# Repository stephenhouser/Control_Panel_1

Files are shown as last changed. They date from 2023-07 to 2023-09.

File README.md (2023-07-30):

# Control Panel

The old-school hard-switch control panel for Home Automation.

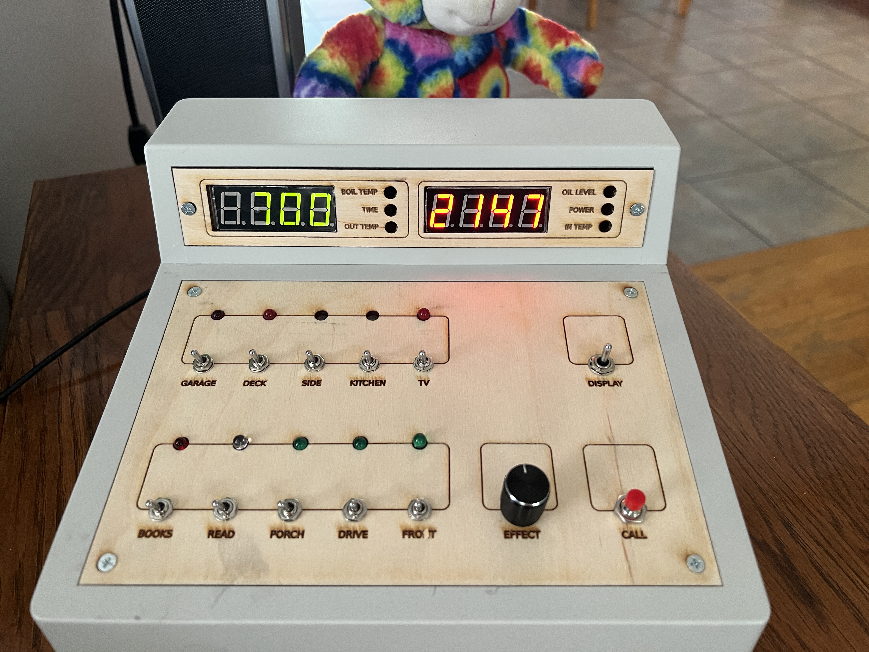
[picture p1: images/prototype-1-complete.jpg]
Breadboard Prototype


This project has a few parts, each documented in their own section below.

- Project Box from Amazon; link and description
- Base and Top panels; SVG files for a laser cutter
- PCBs for Base and Top panels; KiCad PCB designs for manufacture

# Project Box

The project box is a [BUD Industries PC-11495 Plastic Style F Box 9" W x 5" H x 8.5" D, Natural](
https://www.amazon.com/gp/product/B005T98PQS/ref=ppx_yo_dt_b_search_asin_title?ie=UTF8&psc=1) which I found on Amazon for ~$32 USD. The [Dimensions](https://www.budind.com/wp-content/uploads/2019/01/hb11495.pdf) are available from BUD Industries (thank you!)

Another option, without the top display is the [BUD Industries PC-11493 Plastic Style F Box 9" L x 8.5" W x 1.98" H, Natural](https://www.amazon.com/gp/product/B005T592P0/ref=ppx_yo_dt_b_search_asin_title?ie=UTF8&psc=1) for ~$30 USD. The [Dimensions](https://www.budind.com/wp-content/uploads/2019/01/hb11493.pdf) are available from BUD Industries (thank you!)

You can find details on these boxes in general from [BUD Industries](https://www.budind.com/series/general-use-boxes/plasticase-style-f-plastic-cases-2/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)

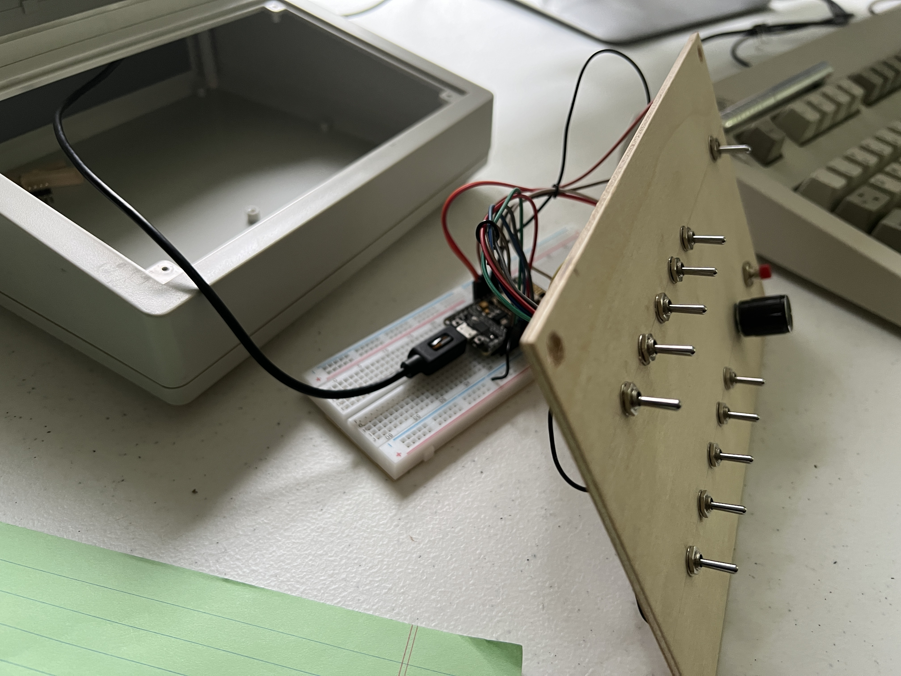
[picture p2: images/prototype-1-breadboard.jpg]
Breadboard Prototype


# Base and Top Panels

Look in the Box_Panels directory. These are SVG files for a laser cutter

# PCBs for Base and Top panels

Uses KiCad v7.x for two PCB's; Control Board and Display Board.

Control Board
---

- Version 1.0 sent to fab on 7/17/2023

Components:

-  1 x ESP32 DevKit C ([Amazon](https://www.amazon.com/AITRIP-ESP32-DevKitC-Development-ESP32-WROOM-32D-Compatible/dp/B08HMJ1X6W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))
- 16 x Addressable RGB LEDs ([sparkfun](https://www.sparkfun.com/products/12986))
- 10 x 2-position SPST Toggle Switches ([Amazon](https://www.amazon.com/MTS-101-Position-Miniature-Toggle-Switch/dp/B0799LBFNY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))
-  1 x 3-position SPST Toggle Switch ([Amazon](https://www.amazon.com/Twidec-Momentary-Miniature-Waterproof-MTS-123-MZ/dp/B07VHCB1Q4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))
- 10 x 1N4148 Diodes
-  1 x Rotary Encoder + Knob ([Amazon](https://www.amazon.com/gp/product/B07DM2YMT4/ref=ppx_yo_dt_b_search_asin_title?ie=UTF8&psc=1))
-  1 x Mini pushbutton switch ([Amazon](https://www.amazon.com/Momentary-Spring-Return-Self-Return-Pushbutton-Switches/dp/B09DJY5Y5L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))

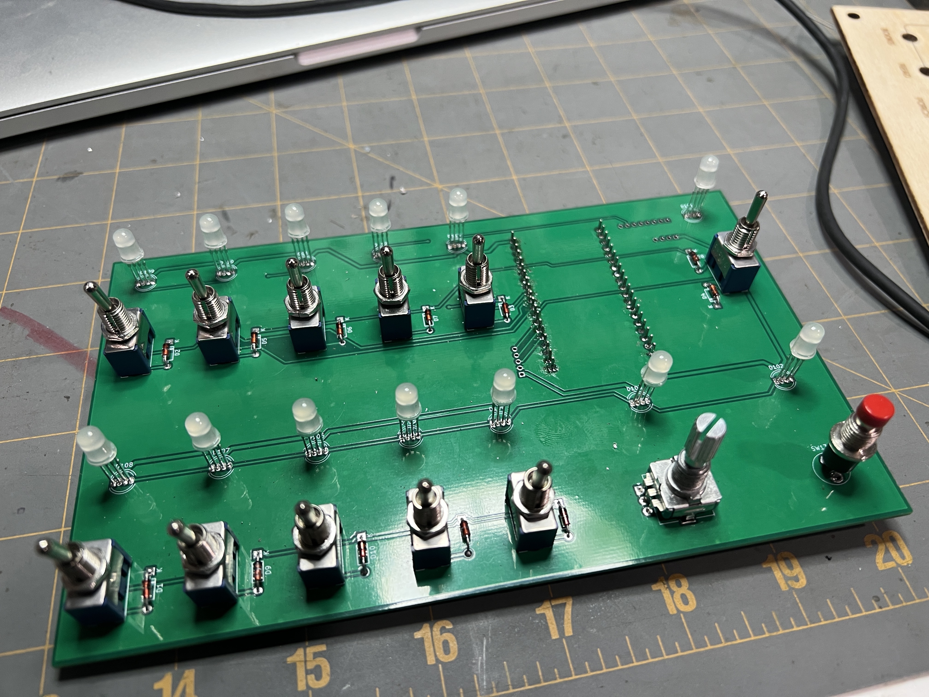
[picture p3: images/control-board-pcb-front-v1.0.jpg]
Control Board PCB Front
)
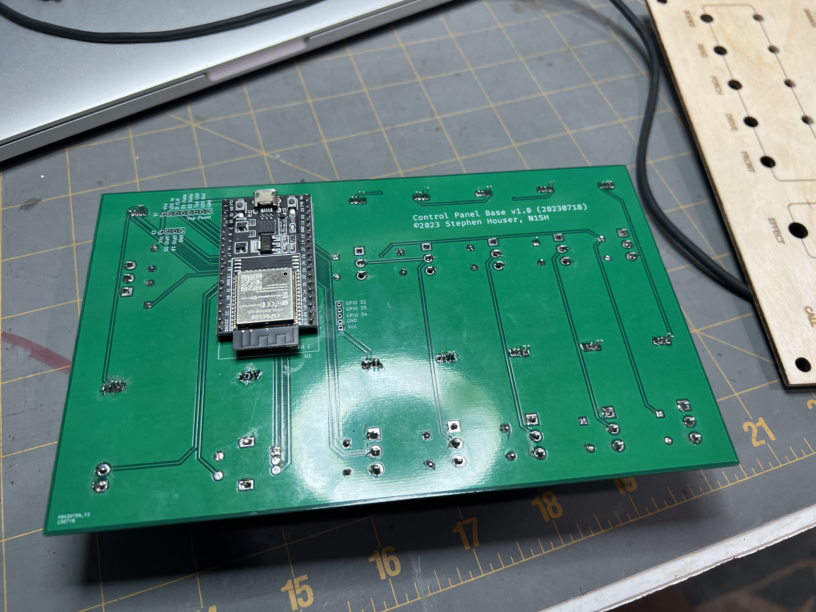
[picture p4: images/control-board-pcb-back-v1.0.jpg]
Control Board PCB Back
)

Display Board
---
Display Board not yet created.

Components:

-  2 x 0.56" LED Display Digital Tube Clock Module 4 Digit ([Amazon](https://www.amazon.com/gp/product/B0BB72R6RW/ref=ppx_yo_dt_b_asin_title_o03_s00?ie=UTF8&psc=1))

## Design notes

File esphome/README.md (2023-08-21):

# ESPHome Control Panel Configuration

This directory holds the configuration for the control panel with [ESPHome](https://esphome.io) and [HomeAssistant](https://www.home-assistant.io).

- **components**: ESPHome custom component for the `matrix_keyboard`. Will need to be copied into the ESPHome directory to be included into the YAML configurations.

- **blueprints**: contains blueprintes for ESPHome to configure each toggle switch to be connected to an LED on the panel and a device within HomeAssistant. Each toggle and it's associated LED should be connected to a `control-panel-switch`

- **common**: contans some common includes to be used in ESPHome. These are optional. If not used, the `include` statements will need to be removed from the YAML files.

- **Example Congifurations**:
  - `living-room-cp.yaml`: Living Room Control Panel (production)
  - `dev-control-panel.yaml`: Development Control Panel (development, Office)
  - `dev-sound.yaml`: Experiment with i2s sound

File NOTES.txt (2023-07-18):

Getting Started in KiCad
https://docs.kicad.org/6.0/en/getting_started_in_kicad/getting_started_in_kicad.html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

in ~/Documents/KiCad
	https://forum.digikey.com/t/importing-the-digi-key-kicad-library-into-kicad-5-0-0/4075
```	
git clone https://github.com/Digi-Key/digikey-kicad-library.git
git clone https://github.com/jdunmire/kicad-ESP8266
```

toggle switch: 
pushbutton: PS1024ALRED, 
https://www.digikey.com/en/products/base-product/e-switch/141/PS1024/476669
https://www.digikey.com/en/products/detail/e-switch/PS1024ALRED/81539
https://media.digikey.com/pdf/Data%20Sheets/E-Switch%20PDFs/PS1024ablk%20Drawing.pdf

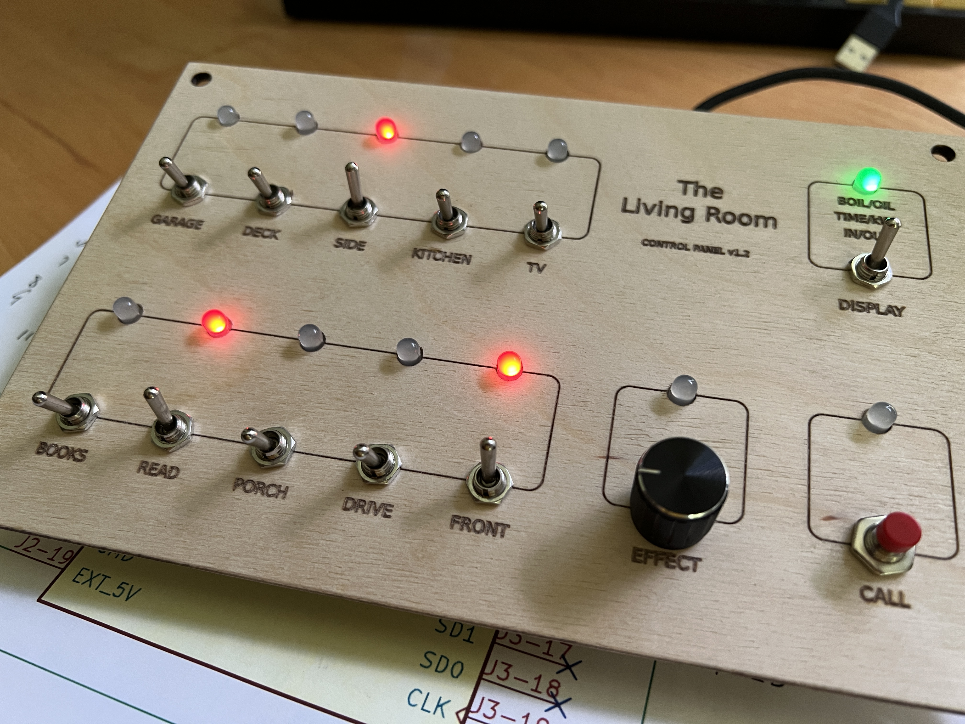
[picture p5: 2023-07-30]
images/control-panel-v1.2.jpg

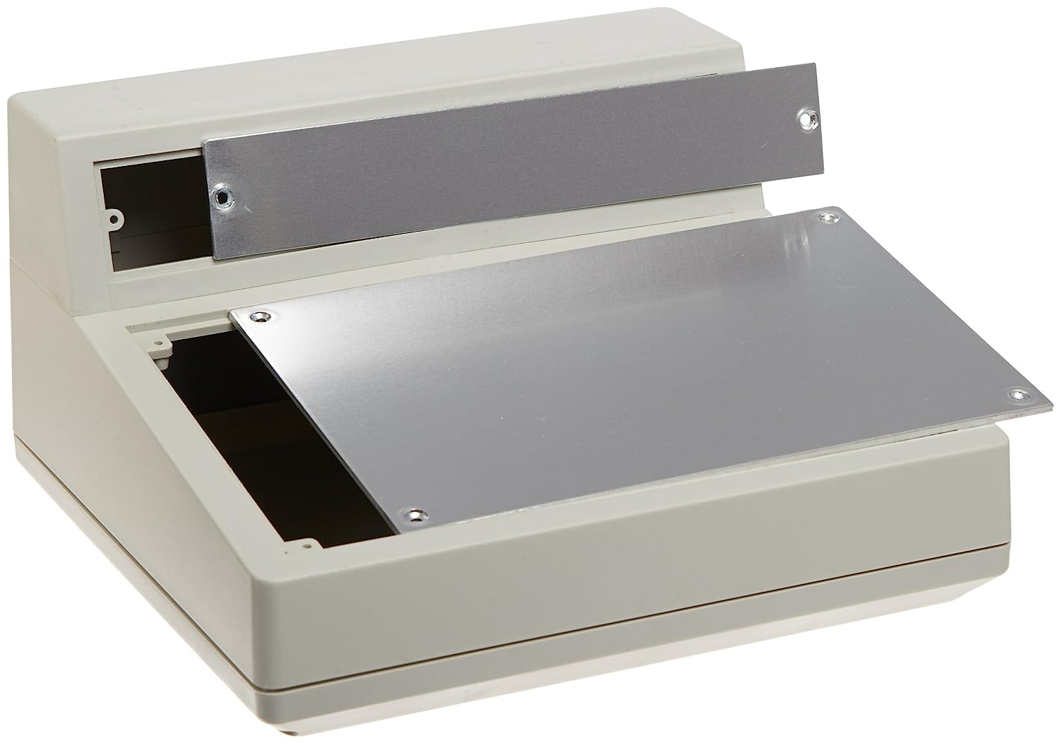
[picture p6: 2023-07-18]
Box_Panels/PC-11495.jpg

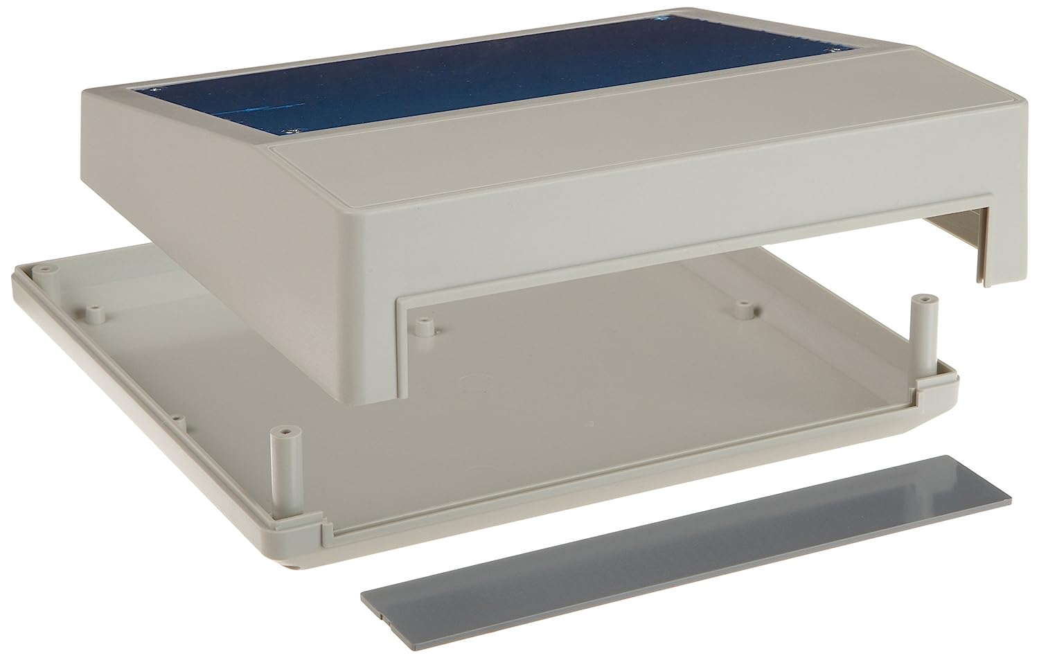
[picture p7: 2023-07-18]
Box_Panels/PC-11493.jpg

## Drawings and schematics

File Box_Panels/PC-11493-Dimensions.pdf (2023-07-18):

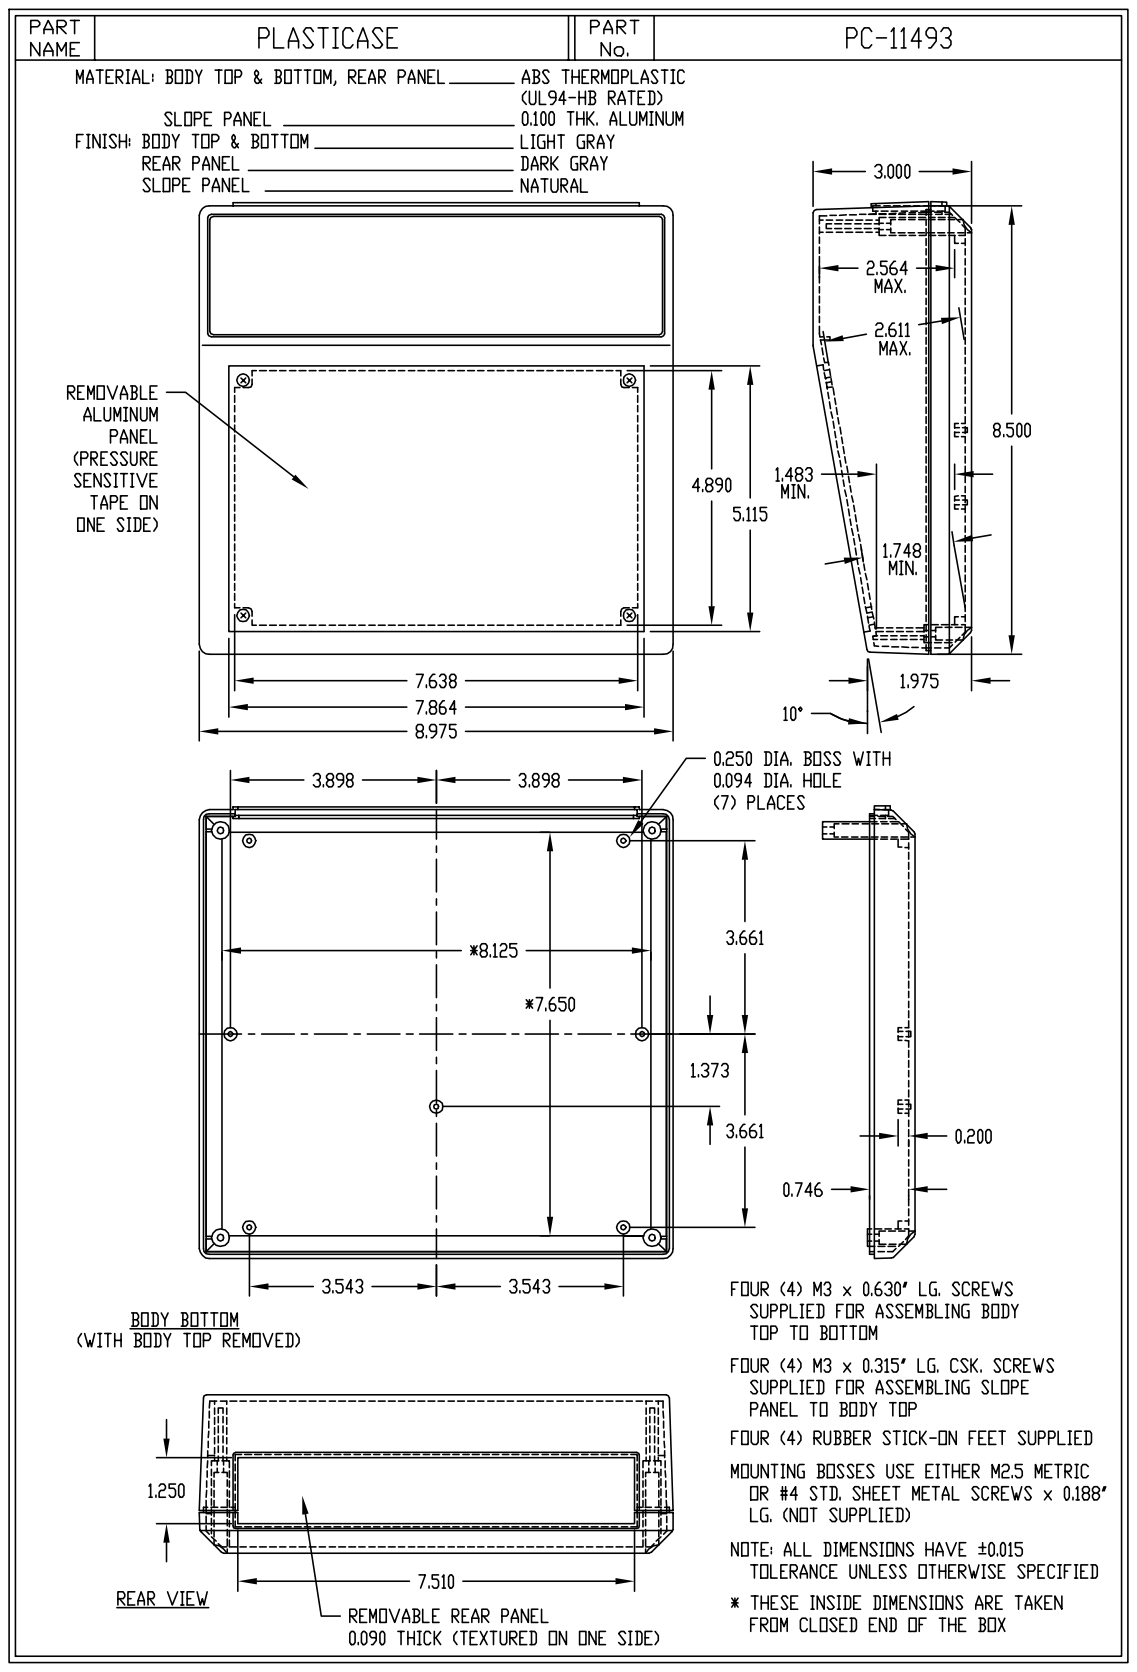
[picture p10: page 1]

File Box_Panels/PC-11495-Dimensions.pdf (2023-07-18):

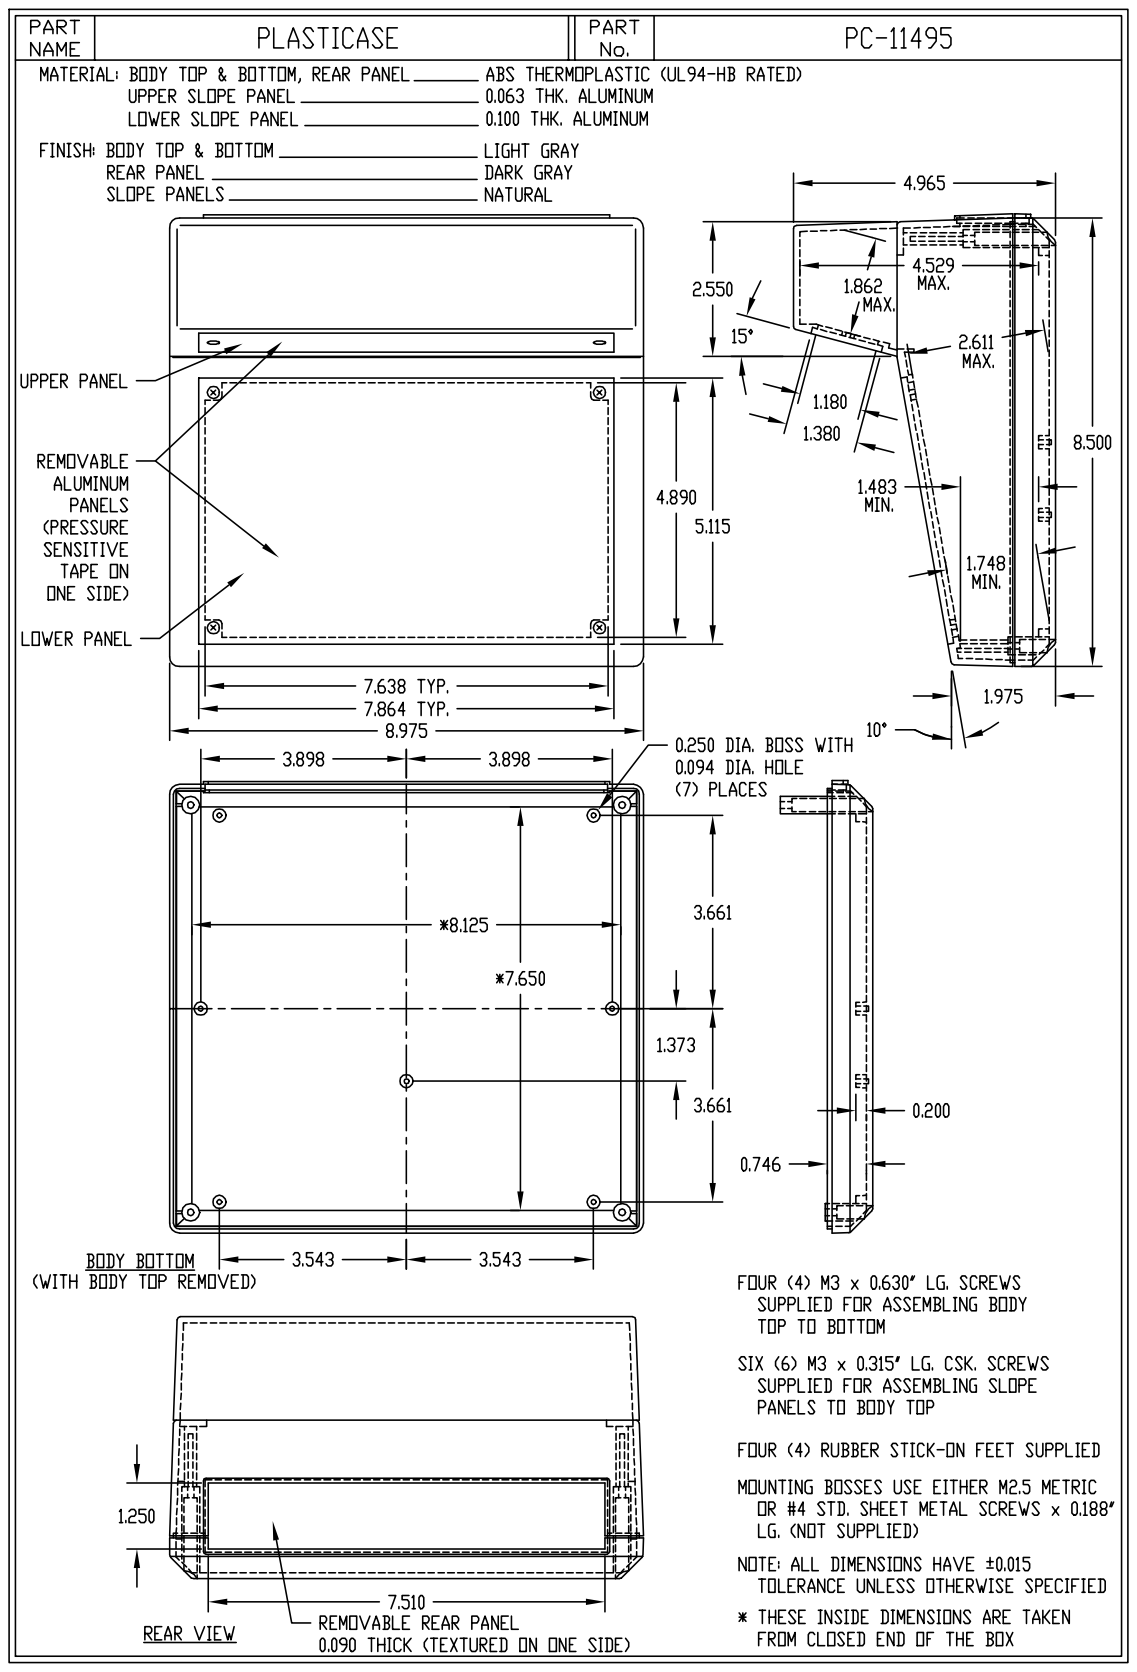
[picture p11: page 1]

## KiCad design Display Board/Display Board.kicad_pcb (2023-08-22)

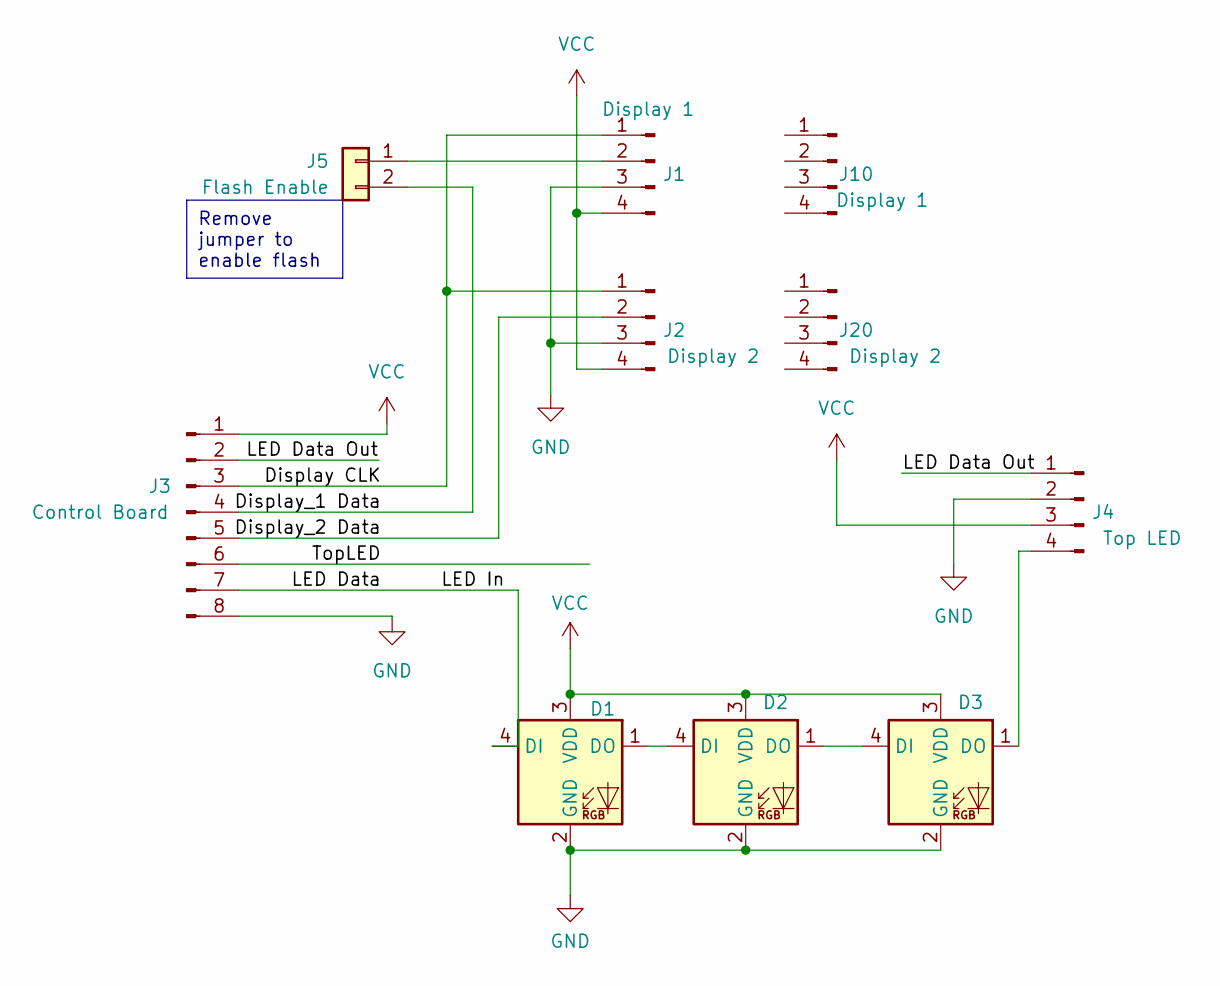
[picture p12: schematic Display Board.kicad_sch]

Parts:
D1, D2, D3: APA-106-F5; LED_D5.0mm-4_RGB
J1, J10: Display 1; PinHeader_1x04_P2.54mm_Vertical
J2, J20: Display 2; PinHeader_1x04_P2.54mm_Vertical
J3: Control Board; PinHeader_1x08_P2.00mm_Vertical
J4: Top LED; PinHeader_1x04_P2.00mm_Vertical
J5: Flash Enable; PinHeader_1x02_P2.54mm_Vertical

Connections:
/Display CLK: J1.1, J2.1, J3.3
/Display_1 Data: J3.4, J5.2
/Display_2 Data: J2.2, J3.5
/LED Data: D1.4 (DI), J3.7
/LED Data Out: J3.2, J4.1
/TopLED: J3.6
GND: D1.2 (GND), D2.2 (GND), D3.2 (GND), J1.3, J2.3, J3.8, J4.2
unnamed: D1.1 (DO), D2.4 (DI)
unnamed: D2.1 (DO), D3.4 (DI)
unnamed: D3.1 (DO), J4.4
unnamed: J1.2, J5.1
VCC: D1.3 (VDD), D2.3 (VDD), D3.3 (VDD), J1.4, J2.4, J3.1, J4.3

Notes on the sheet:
Remove jumper to enable flash

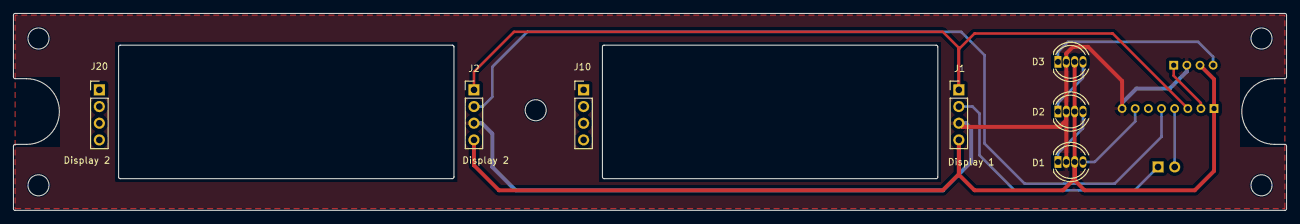
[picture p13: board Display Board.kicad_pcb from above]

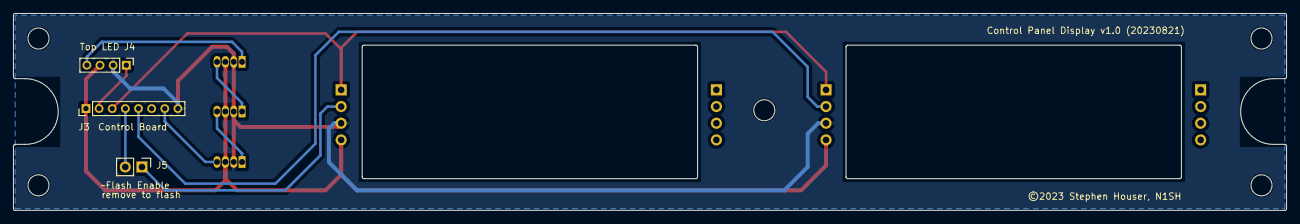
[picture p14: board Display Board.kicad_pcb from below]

Board: 2 copper layers, 193.8 x 30.0 mm, 15 parts (3 on the bottom side), 11 nets.

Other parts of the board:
REF01, REF02, REF03, REF04, REF05: MountingHole_3.2mm_M3

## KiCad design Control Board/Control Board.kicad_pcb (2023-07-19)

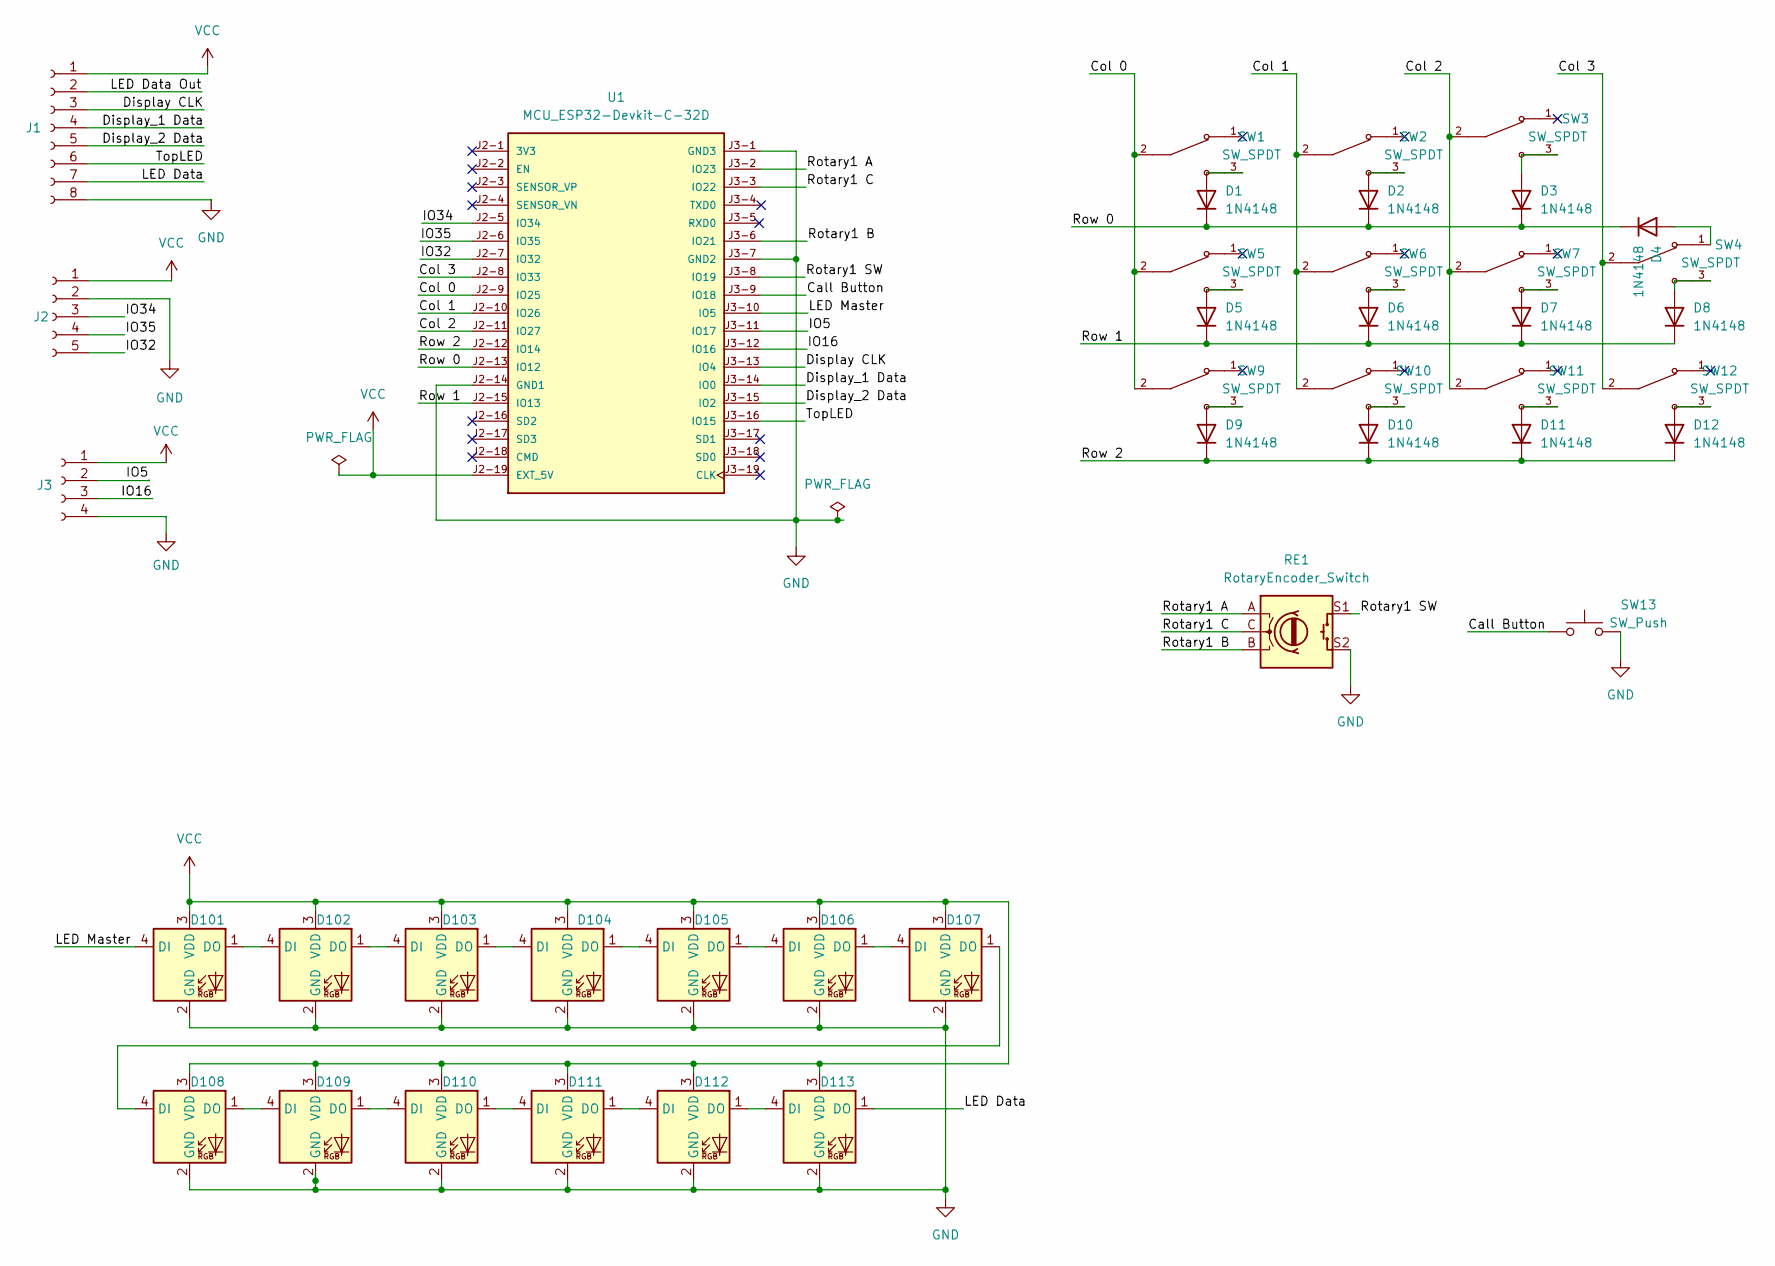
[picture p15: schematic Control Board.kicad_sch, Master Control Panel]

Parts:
D1, D2, D3, D4, D5, D6, D7, D8, D9, D10, D11, D12: 1N4148; D_DO-35_SOD27_P7.62mm_Horizontal
D101, D102, D103, D104, D105, D106, D107, D108, D109, D110, D111, D112, D113: APA-106-F5; LED_D5.0mm-4_RGB
J1: Conn_01x08_Socket; PinHeader_1x08_P2.00mm_Vertical
J2: Conn_01x05_Socket; PinHeader_1x05_P2.00mm_Vertical
J3: Conn_01x04_Socket; PinHeader_1x04_P2.00mm_Vertical
RE1: RotaryEncoder_Switch; RotaryEncoder_Alps_EC11E-Switch_Vertical_H20mm
SW1, SW2: SW_SPDT; SW_Mini_Toggle_100SP1T1B4M2QE; PARTREV E
SW3, SW4, SW5, SW6, SW7, SW9, SW10, SW11, SW12: SW_SPDT; SW_TOGGLE_100SP1T1B4M2QE; PARTREV E
SW13: SW_Push; SW_Mini_Pushbutton_PS1024ALRED
U1: MCU_ESP32-Devkit-C-32D; PARTREV V4

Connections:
/Call Button: SW13.1, U1.J3-9 (IO18)
/Col 0: SW1.2, SW5.2, SW9.2, U1.J2-9 (IO25)
/Col 1: SW2.2, SW6.2, SW10.2, U1.J2-10 (IO26)
/Col 2: SW3.2, SW7.2, SW11.2, U1.J2-11 (IO27)
/Col 3: SW4.2, SW12.2, U1.J2-8 (IO33)
/Display CLK: J1.3, U1.J3-13 (IO4)
/Display_1 Data: J1.4, U1.J3-14 (IO0)
/Display_2 Data: J1.5, U1.J3-15 (IO2)
/IO5: J3.2, U1.J3-11 (IO17)
/IO16: J3.3, U1.J3-12 (IO16)
/IO32: J2.5, U1.J2-7 (IO32)
/IO34: J2.3, U1.J2-5 (IO34)
/IO35: J2.4, U1.J2-6 (IO35)
/LED Data: D113.1 (DO), J1.7
/LED Data Out: J1.2
/LED Master: D101.4 (DI), U1.J3-10 (IO5)
/Rotary1 A: RE1.A, U1.J3-2 (IO23)
/Rotary1 B: RE1.B, U1.J3-6 (IO21)
/Rotary1 C: RE1.C, U1.J3-3 (IO22)
/Rotary1 SW: RE1.S1, U1.J3-8 (IO19)
/Row 0: D1.1 (K), D2.1 (K), D3.1 (K), D4.1 (K), U1.J2-13 (IO12)
/Row 1: D5.1 (K), D6.1 (K), D7.1 (K), D8.1 (K), U1.J2-15 (IO13)
/Row 2: D9.1 (K), D10.1 (K), D11.1 (K), D12.1 (K), U1.J2-12 (IO14)
/TopLED: J1.6, U1.J3-16 (IO15)
GND: D101.2 (GND), D102.2 (GND), D103.2 (GND), D104.2 (GND), D105.2 (GND), D106.2 (GND), D107.2 (GND), D108.2 (GND), D109.2 (GND), D110.2 (GND), D111.2 (GND), D112.2 (GND), D113.2 (GND), J1.8, J2.2, J3.4, RE1.S2, SW13.2, U1.J2-14 (GND1), U1.J3-1 (GND3), U1.J3-7 (GND2)
unnamed: D1.2 (A), SW1.3
unnamed: D2.2 (A), SW2.3
unnamed: D3.2 (A), SW3.3
unnamed: D4.2 (A), SW4.1
unnamed: D5.2 (A), SW5.3
unnamed: D6.2 (A), SW6.3
unnamed: D7.2 (A), SW7.3
unnamed: D8.2 (A), SW4.3
unnamed: D9.2 (A), SW9.3
unnamed: D10.2 (A), SW10.3
unnamed: D11.2 (A), SW11.3
unnamed: D12.2 (A), SW12.3
unnamed: D101.1 (DO), D102.4 (DI)
unnamed: D102.1 (DO), D103.4 (DI)
unnamed: D103.1 (DO), D104.4 (DI)
unnamed: D104.1 (DO), D105.4 (DI)
unnamed: D105.1 (DO), D106.4 (DI)
unnamed: D106.1 (DO), D107.4 (DI)
unnamed: D107.1 (DO), D108.4 (DI)
unnamed: D108.1 (DO), D109.4 (DI)
unnamed: D109.1 (DO), D110.4 (DI)
unnamed: D110.1 (DO), D111.4 (DI)
unnamed: D111.1 (DO), D112.4 (DI)
unnamed: D112.1 (DO), D113.4 (DI)
VCC: D101.3 (VDD), D102.3 (VDD), D103.3 (VDD), D104.3 (VDD), D105.3 (VDD), D106.3 (VDD), D107.3 (VDD), D108.3 (VDD), D109.3 (VDD), D110.3 (VDD), D111.3 (VDD), D112.3 (VDD), D113.3 (VDD), J1.1, J2.1, J3.1, U1.J2-19 (EXT_5V)

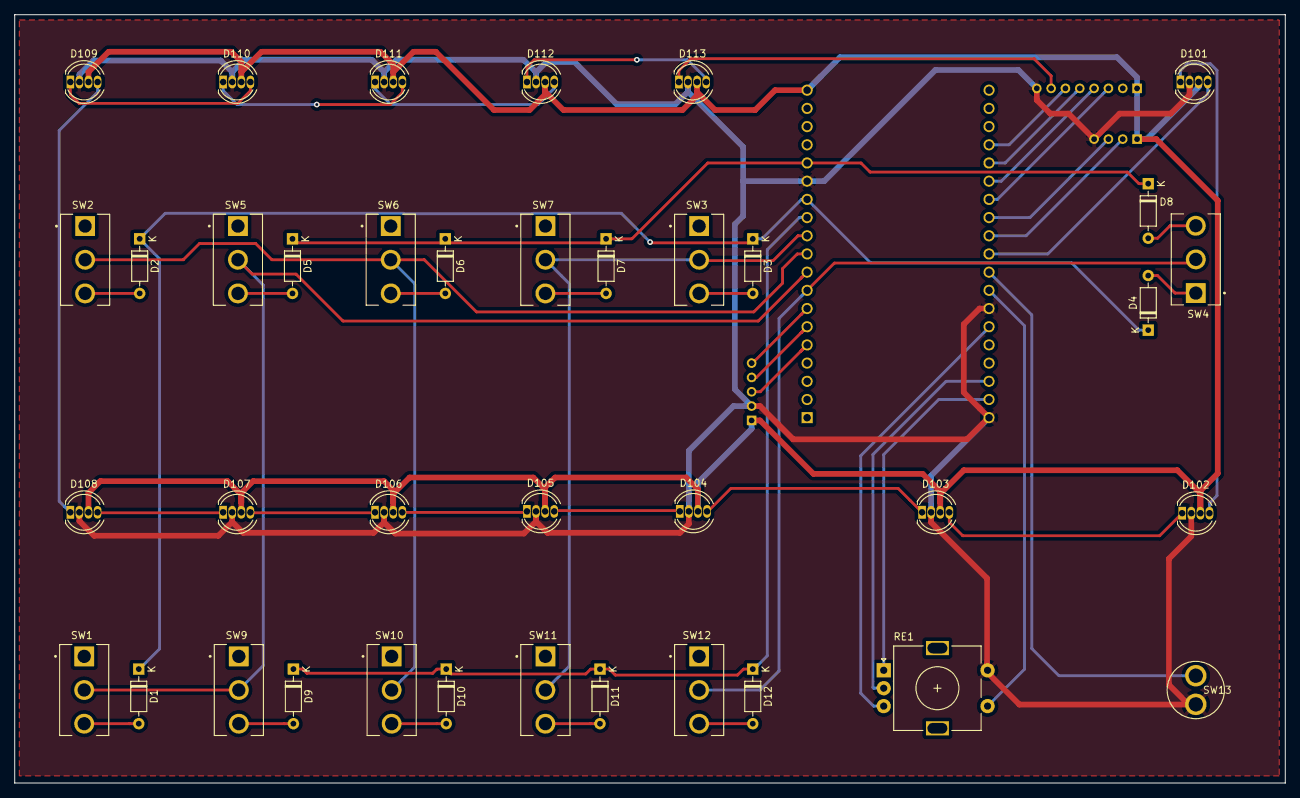
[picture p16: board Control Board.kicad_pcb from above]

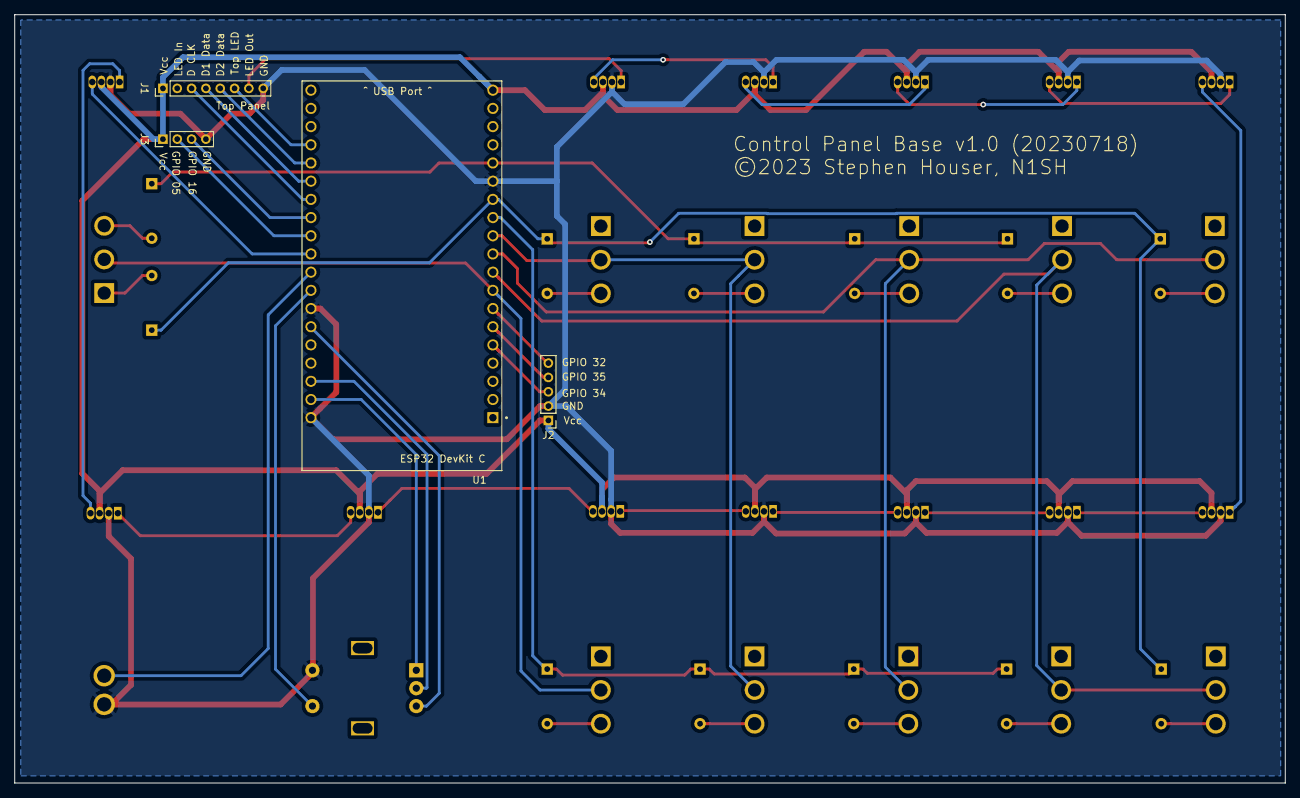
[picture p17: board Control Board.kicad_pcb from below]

Board: 2 copper layers, 177.4 x 107.3 mm, 42 parts (4 on the bottom side), 49 nets.

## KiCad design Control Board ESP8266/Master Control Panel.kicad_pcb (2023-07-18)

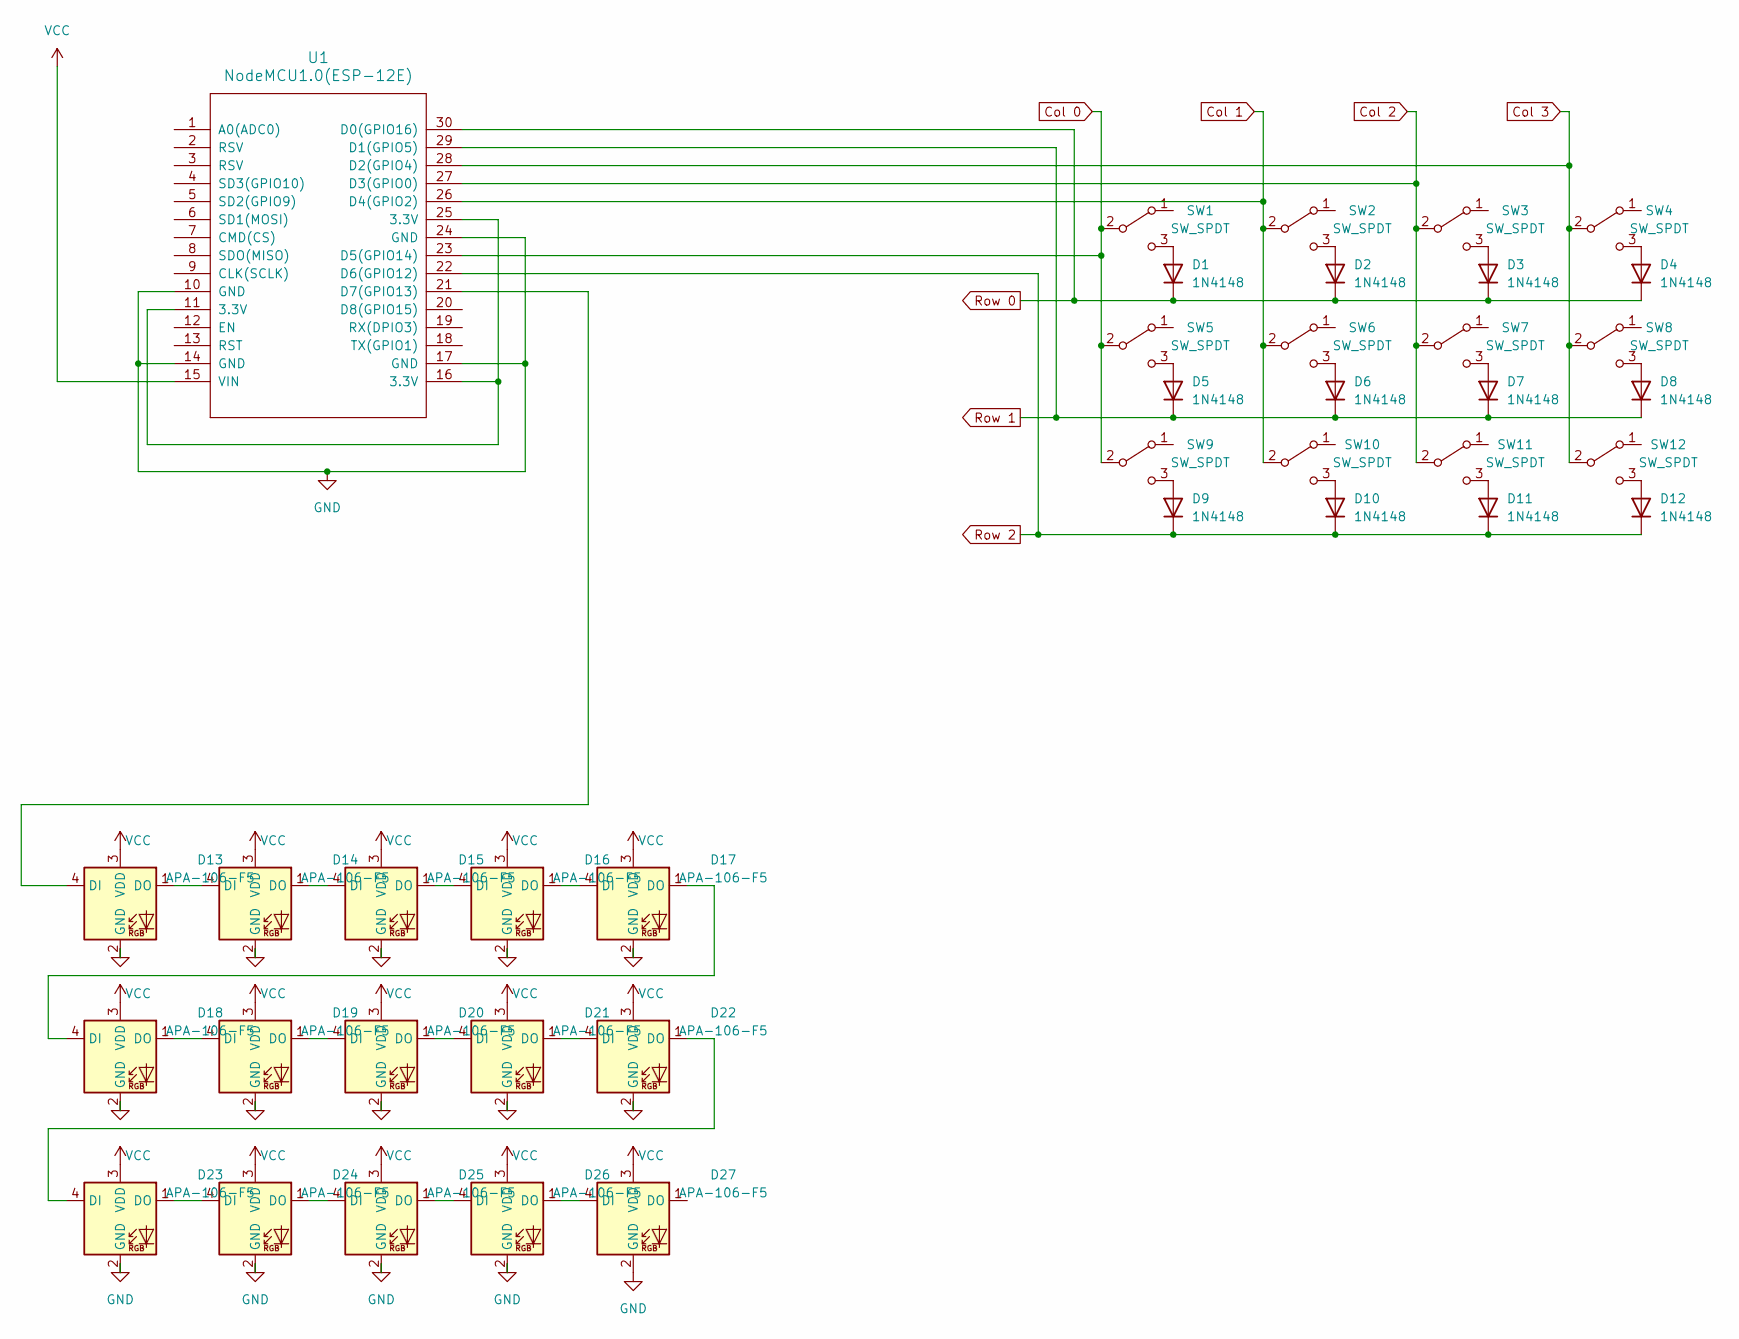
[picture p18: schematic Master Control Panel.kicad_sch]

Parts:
D1, D2, D3, D4, D5, D6, D7, D8, D9, D10, D11, D12: 1N4148; D_DO-35_SOD27_P7.62mm_Horizontal
D13, D14, D15, D16, D17, D18, D19, D20, D21, D22, D23, D24, D25, D26, D27: APA-106-F5; LED_D5.0mm-4_RGB
SW1, SW2, SW3, SW4, SW5, SW6, SW7, SW8, SW9, SW10, SW11, SW12: SW_SPDT; SW_100SP1T1B4M2QE
U1: NodeMCU1.0(ESP-12E); NodeMCU1.0(12-E)

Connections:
Col 0: SW1.2 (B), SW5.2 (B), SW9.2 (B), U1.23 (D5(GPIO14))
Col 1: SW2.2 (B), SW6.2 (B), SW10.2 (B), U1.26 (D4(GPIO2))
Col 2: SW3.2 (B), SW7.2 (B), SW11.2 (B), U1.27 (D3(GPIO0))
Col 3: SW4.2 (B), SW8.2 (B), SW12.2 (B), U1.28 (D2(GPIO4))
GND: D13.2 (GND), D14.2 (GND), D15.2 (GND), D16.2 (GND), D17.2 (GND), D18.2 (GND), D19.2 (GND), D20.2 (GND), D21.2 (GND), D22.2 (GND), D23.2 (GND), D24.2 (GND), D25.2 (GND), D26.2 (GND), D27.2 (GND), U1.10 (GND), U1.14 (GND), U1.17 (GND), U1.24 (GND)
unnamed: D1.2 (A), SW1.3 (C)
unnamed: D2.2 (A), SW2.3 (C)
unnamed: D3.2 (A), SW3.3 (C)
unnamed: D4.2 (A), SW4.3 (C)
unnamed: D5.2 (A), SW5.3 (C)
unnamed: D6.2 (A), SW6.3 (C)
unnamed: D7.2 (A), SW7.3 (C)
unnamed: D8.2 (A), SW8.3 (C)
unnamed: D9.2 (A), SW9.3 (C)
unnamed: D10.2 (A), SW10.3 (C)
unnamed: D11.2 (A), SW11.3 (C)
unnamed: D12.2 (A), SW12.3 (C)
unnamed: D13.4 (DI), U1.21 (D7(GPIO13))
unnamed: D13.1 (DO), D14.4 (DI)
unnamed: D14.1 (DO), D15.4 (DI)
unnamed: D15.1 (DO), D16.4 (DI)
unnamed: D16.1 (DO), D17.4 (DI)
unnamed: D17.1 (DO), D18.4 (DI)
unnamed: D18.1 (DO), D19.4 (DI)
unnamed: D19.1 (DO), D20.4 (DI)
unnamed: D20.1 (DO), D21.4 (DI)
unnamed: D21.1 (DO), D22.4 (DI)
unnamed: D22.1 (DO), D23.4 (DI)
unnamed: D23.1 (DO), D24.4 (DI)
unnamed: D24.1 (DO), D25.4 (DI)
unnamed: D25.1 (DO), D26.4 (DI)
unnamed: D26.1 (DO), D27.4 (DI)
unnamed: U1.11 (3.3V), U1.16 (3.3V), U1.25 (3.3V)
Row 0: D1.1 (K), D2.1 (K), D3.1 (K), D4.1 (K), U1.30 (D0(GPIO16))
Row 1: D5.1 (K), D6.1 (K), D7.1 (K), D8.1 (K), U1.29 (D1(GPIO5))
Row 2: D9.1 (K), D10.1 (K), D11.1 (K), D12.1 (K), U1.22 (D6(GPIO12))
VCC: D13.3 (VDD), D14.3 (VDD), D15.3 (VDD), D16.3 (VDD), D17.3 (VDD), D18.3 (VDD), D19.3 (VDD), D20.3 (VDD), D21.3 (VDD), D22.3 (VDD), D23.3 (VDD), D24.3 (VDD), D25.3 (VDD), D26.3 (VDD), D27.3 (VDD), U1.15 (VIN)

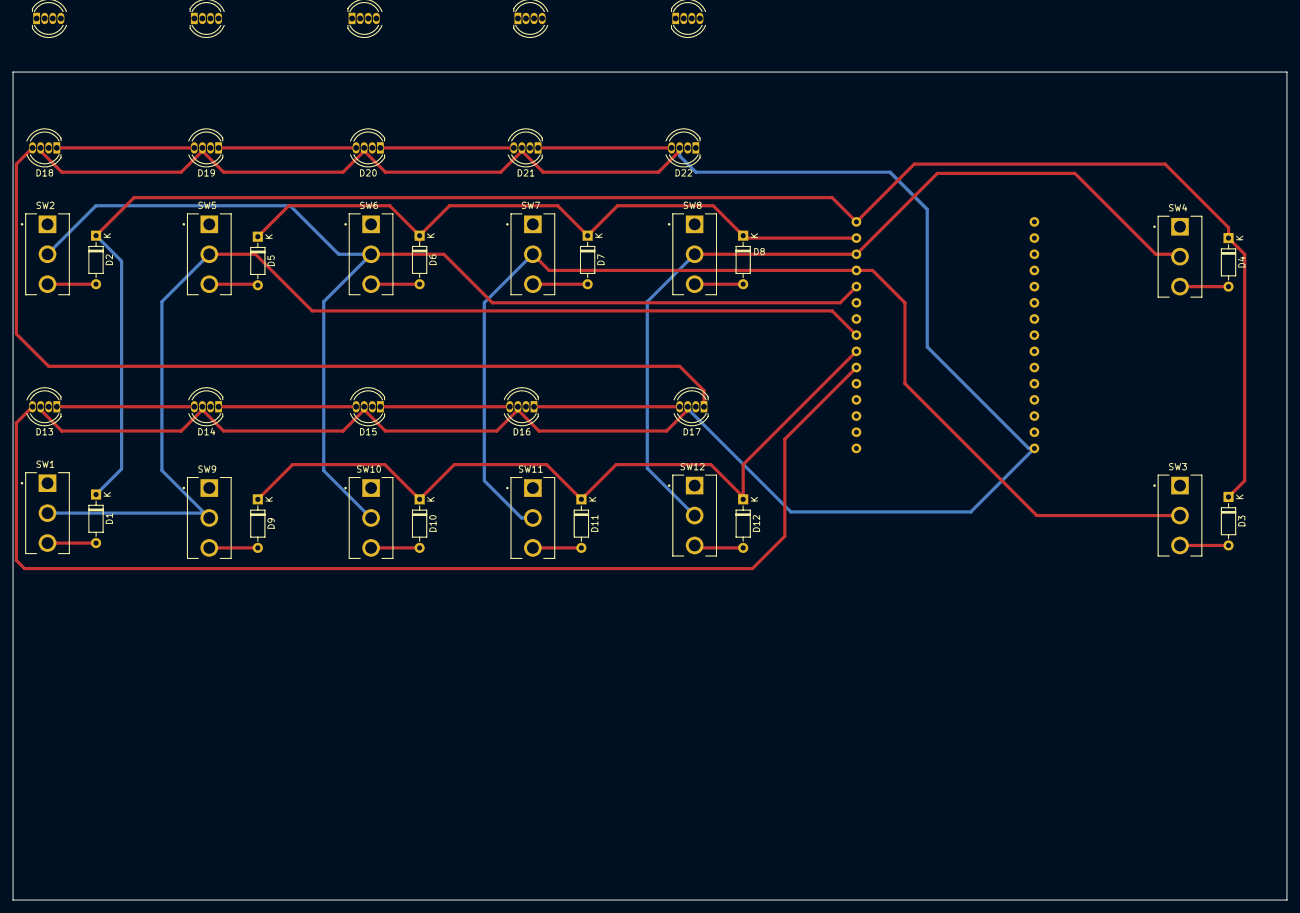
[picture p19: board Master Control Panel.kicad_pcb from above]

Board: 2 copper layers, 200.0 x 130.0 mm, 40 parts (1 on the bottom side), 37 nets.

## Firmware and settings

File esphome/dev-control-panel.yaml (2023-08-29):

# control-panel.yaml - ESPHome configuration for the Control Panel v1
# 
# 2023/07/24 Stephen Houser
substitutions:
  device_name: "dev-control-panel"
  friendly_name: "Dev Control Panel"
  friendly_short: "dev_control_panel"
  display_a_sensor: "sensor.dev_control_panel_display_a"
  display_b_sensor: "sensor.dev_control_panel_display_b"

esphome:
  name: ${device_name}
  friendly_name: ${friendly_name}
  on_boot:
    if:
      condition:
        api.connected:
      then:
        - logger.log: API connected.
        - light.turn_on: 
            id: panel_leds
            red: 0
            green: 1
            blue: 0
        - delay: 1s
        - light.turn_off: panel_leds

esp32:
  board: esp32dev
  framework:
    type: arduino

logger:
  # Enable logger

wifi:
  # WiFi settings are mostly secrets
  ssid: !secret wifi_ssid
  password: !secret wifi_password
  # fast_connect helps with connection to hidden SSID
  fast_connect: True
  # force the network name to be on hidden network
  use_address: ${device_name}.playmates

ota:
  # Enable Over The Air (OTA) updates with password
  password: !secret ota_password

api:
  # Enable Encrypted Home Assistant API
  encryption:
    key: "G+UNlM3nwQwj87nA+e9PllL1n7BNlsvfkPNOTAX8yG0="

# mqtt:
#   # Secret MQTT server parameters
#   broker: !secret mqtt_host
#   username: !secret mqtt_user
#   password: !secret mqtt_password

web_server:
  # Web interface enabled and has local resources (no Internet)
  local: True
  include_internal: True

external_components:
  # use all components from a local folder
  - source:
      type: local
      path: components
    components: [ matrix_keyboard ]

globals:
  - id: led_bright
    type: int
    restore_value: True
    initial_value: '15'

  - id: display_bright
    type: int
    restore_value: True
    initial_value: '1'

time:
  - platform: homeassistant
    id: homeassistant_time

switch:
  # Allow remote restart (from web interface also)
  - platform: restart
    name: "${friendly_name} Restart"

output:
  # Configure GPIO21 as an output to pull it low and enable the rotary encoder
  # Could have just wired this to ground on the PCB, but it's wired to a pin.
  - platform: gpio
    pin: GPIO22
    id: rotarty_encoder_enable

light:
  # The Addressable RGB lights on the control panel. All in one "strip"
  - platform: esp32_rmt_led_strip
    rgb_order: RGB
    pin: GPIO5
    id: panel_leds
    # 13 LEDs in control panel; 6 in display panel
    num_leds: 17
    rmt_channel: 0
    chipset: ws2812
    name: "Panel LEDs"
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

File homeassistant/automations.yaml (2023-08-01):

# automations.yaml - sample control panel automations
# automations used to tie switches to devices
# These are based on the blueprint `control-panel-switch.yaml`
#
- id: '1690839798830'
  alias: Control Panel SW0 (Garage Side Light)
  description: ''
  use_blueprint:
    path: stephenhouser/control-panel-switch.yaml
    input:
      led_color:
      - 0
      - 255
      - 0
      sync_color:
      - 255
      - 0
      - 0
      led_brightness: 32
      panel_led: light.control_panel_1_light_sw0
      panel_switch: binary_sensor.control_panel_1_switch_sw0
      target_device: light.garage_side_switch
- id: '1690839798831'
  alias: Control Panel SW1 (Back Deck Light)
  description: ''
  use_blueprint:
    path: stephenhouser/control-panel-switch.yaml
    input:
      led_color:
      - 0
      - 255
      - 0
      sync_color:
      - 255
      - 0
      - 0
      led_brightness: 32
      panel_led: light.control_panel_1_light_sw1
      panel_switch: binary_sensor.control_panel_1_switch_sw1
      target_device: light.back_door_light
- id: '1690839798832'
  alias: Control Panel SW2 (Backyard/Side Light)
  description: ''
  use_blueprint:
    path: stephenhouser/control-panel-switch.yaml
    input:
      led_color:
      - 0
      - 255
      - 0
      sync_color:
      - 255
      - 0
      - 0
      led_brightness: 32
      panel_led: light.control_panel_1_light_sw2
      panel_switch: binary_sensor.control_panel_1_switch_sw2
      target_device: light.backyard_light
- id: '1690839798833'
  alias: Control Panel SW3 (Kitchen Candles)
  description: ''
  use_blueprint:
    path: stephenhouser/control-panel-switch.yaml
    input:
      led_color:
      - 0
      - 255
      - 0
      sync_color:
      - 255
      - 0
      - 0
      led_brightness: 32
      panel_led: light.control_panel_1_light_sw3
      panel_switch: binary_sensor.control_panel_1_switch_sw3
      target_device: light.kitchen_led_master
- id: '1690839798834'
  alias: Control Panel SW4 (TV Power)
  description: ''
  use_blueprint:
    path: stephenhouser/control-panel-switch.yaml
    input:
      led_color:
      - 0
      - 255
      - 0
      sync_color:
      - 255
      - 0
      - 0
      led_brightness: 32
      panel_led: light.control_panel_1_light_sw4
      panel_switch: binary_sensor.control_panel_1_switch_sw4
      target_device: switch.tv_power_strip
- id: '1690839798827'
  alias: Control Panel SW5 (Bookcase Lights)
  description: ''
  use_blueprint:
    path: stephenhouser/control-panel-switch.yaml
    input:
      led_color:
      - 0
      - 255
      - 0
      sync_color:
      - 255
      - 0
      - 0
      led_brightness: 32
      panel_led: light.control_panel_1_light_sw5
      panel_switch: binary_sensor.control_panel_1_switch_sw5
      target_device: light.bookcase_lights_2
- id: '1690839798828'
  alias: Control Panel SW6 (Reading Lamp Left)
  description: ''
  use_blueprint:
    path: stephenhouser/control-panel-switch.yaml
    input:
      led_color:
      - 0
      - 255
      - 0
      sync_color:
      - 255
      - 0
      - 0
      led_brightness: 32
      panel_led: light.control_panel_1_light_sw6
      panel_switch: binary_sensor.control_panel_1_switch_sw6
      target_device: light.reading_lamp_left
- id: '1690839798829'
  alias: Control Panel SW6 (Reading Lamp Right)
  description: ''
  use_blueprint:
    path: stephenhouser/control-panel-switch.yaml
    input:
      led_color:
      - 0
      - 255
      - 0
      sync_color:
      - 255
      - 0
      - 0
      led_brightness: 32
      panel_led: light.control_panel_1_light_sw6
      panel_switch: binary_sensor.control_panel_1_switch_sw6
      target_device: light.reading_lamp_right
- id: '1690839798837'
  alias: Control Panel SW7 (Mudroom Deck)
  description: ''
  use_blueprint:
    path: stephenhouser/control-panel-switch.yaml
    input:
      led_color:
      - 0
      - 255
      - 0
      sync_color:
      - 255
      - 0
      - 0
      led_brightness: 32
      panel_led: light.control_panel_1_light_sw7
      panel_switch: binary_sensor.control_panel_1_switch_sw7
      target_device: light.mudroom_deck_light
- id: '1690839798838'
  alias: Control Panel SW8 (Driveway Lights)
  description: ''
  use_blueprint:
    path: stephenhouser/control-panel-switch.yaml
    input:
      led_color:
      - 0
      - 255
      - 0
      sync_color:
      - 255
      - 0
      - 0
      led_brightness: 32
      panel_led: light.control_panel_1_light_sw8
      panel_switch: binary_sensor.control_panel_1_switch_sw8
      target_device: light.garage_front_switch
- id: '1690839798839'
  alias: Control Panel SW9 (Front Porch)
  description: ''
  use_blueprint:
    path: stephenhouser/control-panel-switch.yaml
    input:
      led_color:
      - 0
      - 255
      - 0
      sync_color:
      - 255
      - 0
      - 0
      led_brightness: 32
      panel_led: light.control_panel_1_light_sw9
      panel_switch: binary_sensor.control_panel_1_switch_sw9
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

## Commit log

2023-07-19 rename to control board
    [Control Board-20230716.kicad_pcb, Control Board.kicad_pcb, Control Board.kicad_sch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]
2023-07-19 add initial display board
    [Display Board.kicad_pcb, Display Board.kicad_sch]
2023-07-20 update display board
    [Display Board.kicad_pcb, Display Board.kicad_sch]
2023-07-28 add led to keyboard
2023-07-30 add leds and some samples
2023-08-01 add sample automation
2023-08-21 working on display board and mounting
    [Display Board.kicad_pcb, Display Board.kicad_sch]
2023-08-21 update display board with mounting holes and copper pour
    [Display Board.kicad_pcb, Display Board.kicad_sch]
2023-08-29 tweaking top led

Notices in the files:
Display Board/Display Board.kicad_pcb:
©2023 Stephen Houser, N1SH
